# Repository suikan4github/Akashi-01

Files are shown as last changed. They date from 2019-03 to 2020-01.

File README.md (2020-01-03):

# Akashi-01
A Test jig board for the Murasaki library. Testing I2C, SPI, and UART on the Nucleo 64. This project is for Murasaki development. Not for the Murasaki application developer. 

## Functionality
This board is designed to test the serial port's functionality of the STM32 series MCU. The connectors can be directly mounted on the Nucleo 64 series board. With this board, the following can be tested :
- Serial Port TX and RX. With/without hardware handshake.
- I2C port Master and Slave. 
- SPI port Master and Slave. 

All above are achieved by connecting peripheral port head-to-head ( Serial port is an exception. It just tied TX to RX and RTS to CTS respectively). In addition to these test feature, additional parts can be mount : 
- Serial 7 segments LED display by Spark fun. 
- Rotary encoder with a switch to test the encoder functionality of timer and EXTI (External Interrupt of the STM32 MCU). 

## Development
- [KiCad 5.1](http://kicad-pcb.org/blog/2019/03/KiCad-5.1.0-Release/)
- [Nucleo F091RC](https://www.st.com/ja/evaluation-tools/nucleo-f091rc.html)
- [Nucleo L152RE](https://www.st.com/ja/evaluation-tools/nucleo-l152re.html)
- [Nucleo F446RE](https://www.st.com/ja/evaluation-tools/nucleo-f446re.html)

The schematics [can be downloaded](docs/Akashi-01.pdf) as PDF format. 

## Usage
The test program works with this board will be published as [murasaki_test_fundamental](https://github.com/suikan4github/murasaki_test_foundemental) project in future. 

If you develop a software works with this board, that software has to follow the pin configuration below. Note that the master-slave configuration is critical. If wrong, the MCU may be broken. 

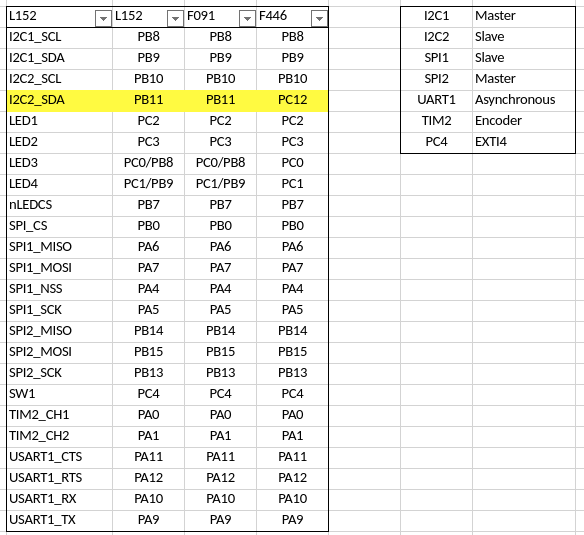
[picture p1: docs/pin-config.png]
Pin Configurations


I2C2_SDA is PB11 for both Nucleo L152RE and F091RC. But it is PC12 for the Nucleo F446RE.

**CAUTION** : Nucleo F446 CN10 pin 18 have to be cut. This pin is connected to VCAP1 pin of the STM32F446 internally. The VCAP1 is not for the peripheral usage. Thus, cutting pin 18 is not problem.

## License
This PCB design is released under the [Creative Commons Attribution 4.0 International license](https://creativecommons.org/licenses/by/4.0/). You are welcome to use this design for commercial purposes.

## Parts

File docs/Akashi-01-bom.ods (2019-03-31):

Reference | Value | Footprint | Datasheet | Field4
C1 | 0.01u | Capacitor_THT:C_Disc_D3.8mm_W2.6mm_P2.50mm | pin pitch = 2.50mm
C2 | 0.01u | Capacitor_THT:C_Disc_D3.8mm_W2.6mm_P2.50mm | pin pitch = 2.50mm
CN10 | PPPC192LFBN-RC | Connector_PinSocket_2.54mm:PinSocket_2x19_P2.54mm_Vertical | https://www.digikey.jp/product-detail/ja/sullins-connector-solutions/PPPC192LFBN-RC/S7122-ND/810258
CN7 | PPPC192LFBN-RC | Connector_PinSocket_2.54mm:PinSocket_2x19_P2.54mm_Vertical | https://www.digikey.jp/product-detail/ja/sullins-connector-solutions/PPPC192LFBN-RC/S7122-ND/810258
D1 | LED | LED_THT:LED_D3.0mm_Clear | pin pitch = 2.54mm
D2 | LED | LED_THT:LED_D3.0mm_Clear | pin pitch = 2.54mm
D3 | LED | LED_THT:LED_D3.0mm_Clear | pin pitch = 2.54mm
D4 | LED | LED_THT:LED_D3.0mm_Clear | pin pitch = 2.54mm
LED1 | SparkFun-7-Segment-Serial-Display-Red | Display_Modules:SparkFun-7-Segment-Serial-Display | https://www.sparkfun.com/products/11441 | COM-11441
R1 | 1k | Resistor_THT:R_Axial_DIN0207_L6.3mm_D2.5mm_P10.16mm_Horizontal | ¼ or 1/8 W
R10 | 10k | Resistor_THT:R_Axial_DIN0207_L6.3mm_D2.5mm_P10.16mm_Horizontal | ¼ or 1/8 W
R11 | 4.7k | Resistor_THT:R_Axial_DIN0207_L6.3mm_D2.5mm_P10.16mm_Horizontal | ¼ or 1/8 W
R2 | 1k | Resistor_THT:R_Axial_DIN0207_L6.3mm_D2.5mm_P10.16mm_Horizontal | ¼ or 1/8 W
R3 | 1k | Resistor_THT:R_Axial_DIN0207_L6.3mm_D2.5mm_P10.16mm_Horizontal | ¼ or 1/8 W
R4 | 1k | Resistor_THT:R_Axial_DIN0207_L6.3mm_D2.5mm_P10.16mm_Horizontal | ¼ or 1/8 W
R5 | 2.2k | Resistor_THT:R_Axial_DIN0207_L6.3mm_D2.5mm_P10.16mm_Horizontal | ¼ or 1/8 W
R6 | 10k | Resistor_THT:R_Axial_DIN0207_L6.3mm_D2.5mm_P10.16mm_Horizontal | ¼ or 1/8 W
R7 | 10k | Resistor_THT:R_Axial_DIN0207_L6.3mm_D2.5mm_P10.16mm_Horizontal | ¼ or 1/8 W
R8 | 10k | Resistor_THT:R_Axial_DIN0207_L6.3mm_D2.5mm_P10.16mm_Horizontal | ¼ or 1/8 W
R9 | 2.2k | Resistor_THT:R_Axial_DIN0207_L6.3mm_D2.5mm_P10.16mm_Horizontal | ¼ or 1/8 W
SW1 | PEC11R-4220F-S0024 | Rotary_Encoder:RotaryEncoder_Alps_EC12E-Switch_Vertical_H20mm_CircularMountingHoles | https://www.digikey.jp/products/ja?keywords=PEC11R-4220F-s0024
TP1 | nSS | TestPoint:TestPoint_THTPad_D1.5mm_Drill0.7mm | ~
TP10 | MOSI | TestPoint:TestPoint_THTPad_D1.5mm_Drill0.7mm | ~
TP11 | GND | TestPoint:TestPoint_THTPad_D1.5mm_Drill0.7mm | ~
TP12 | GND | TestPoint:TestPoint_THTPad_D1.5mm_Drill0.7mm | ~
TP2 | CH1 | TestPoint:TestPoint_THTPad_D1.5mm_Drill0.7mm | ~
TP3 | CH2 | TestPoint:TestPoint_THTPad_D1.5mm_Drill0.7mm | ~
TP4 | SCL | TestPoint:TestPoint_THTPad_D1.5mm_Drill0.7mm | ~
TP5 | TX | TestPoint:TestPoint_THTPad_D1.5mm_Drill0.7mm | ~
TP6 | SDA | TestPoint:TestPoint_THTPad_D1.5mm_Drill0.7mm | ~
TP7 | SCK | TestPoint:TestPoint_THTPad_D1.5mm_Drill0.7mm | ~
TP8 | RTS | TestPoint:TestPoint_THTPad_D1.5mm_Drill0.7mm | ~
TP9 | MISO | TestPoint:TestPoint_THTPad_D1.5mm_Drill0.7mm | ~

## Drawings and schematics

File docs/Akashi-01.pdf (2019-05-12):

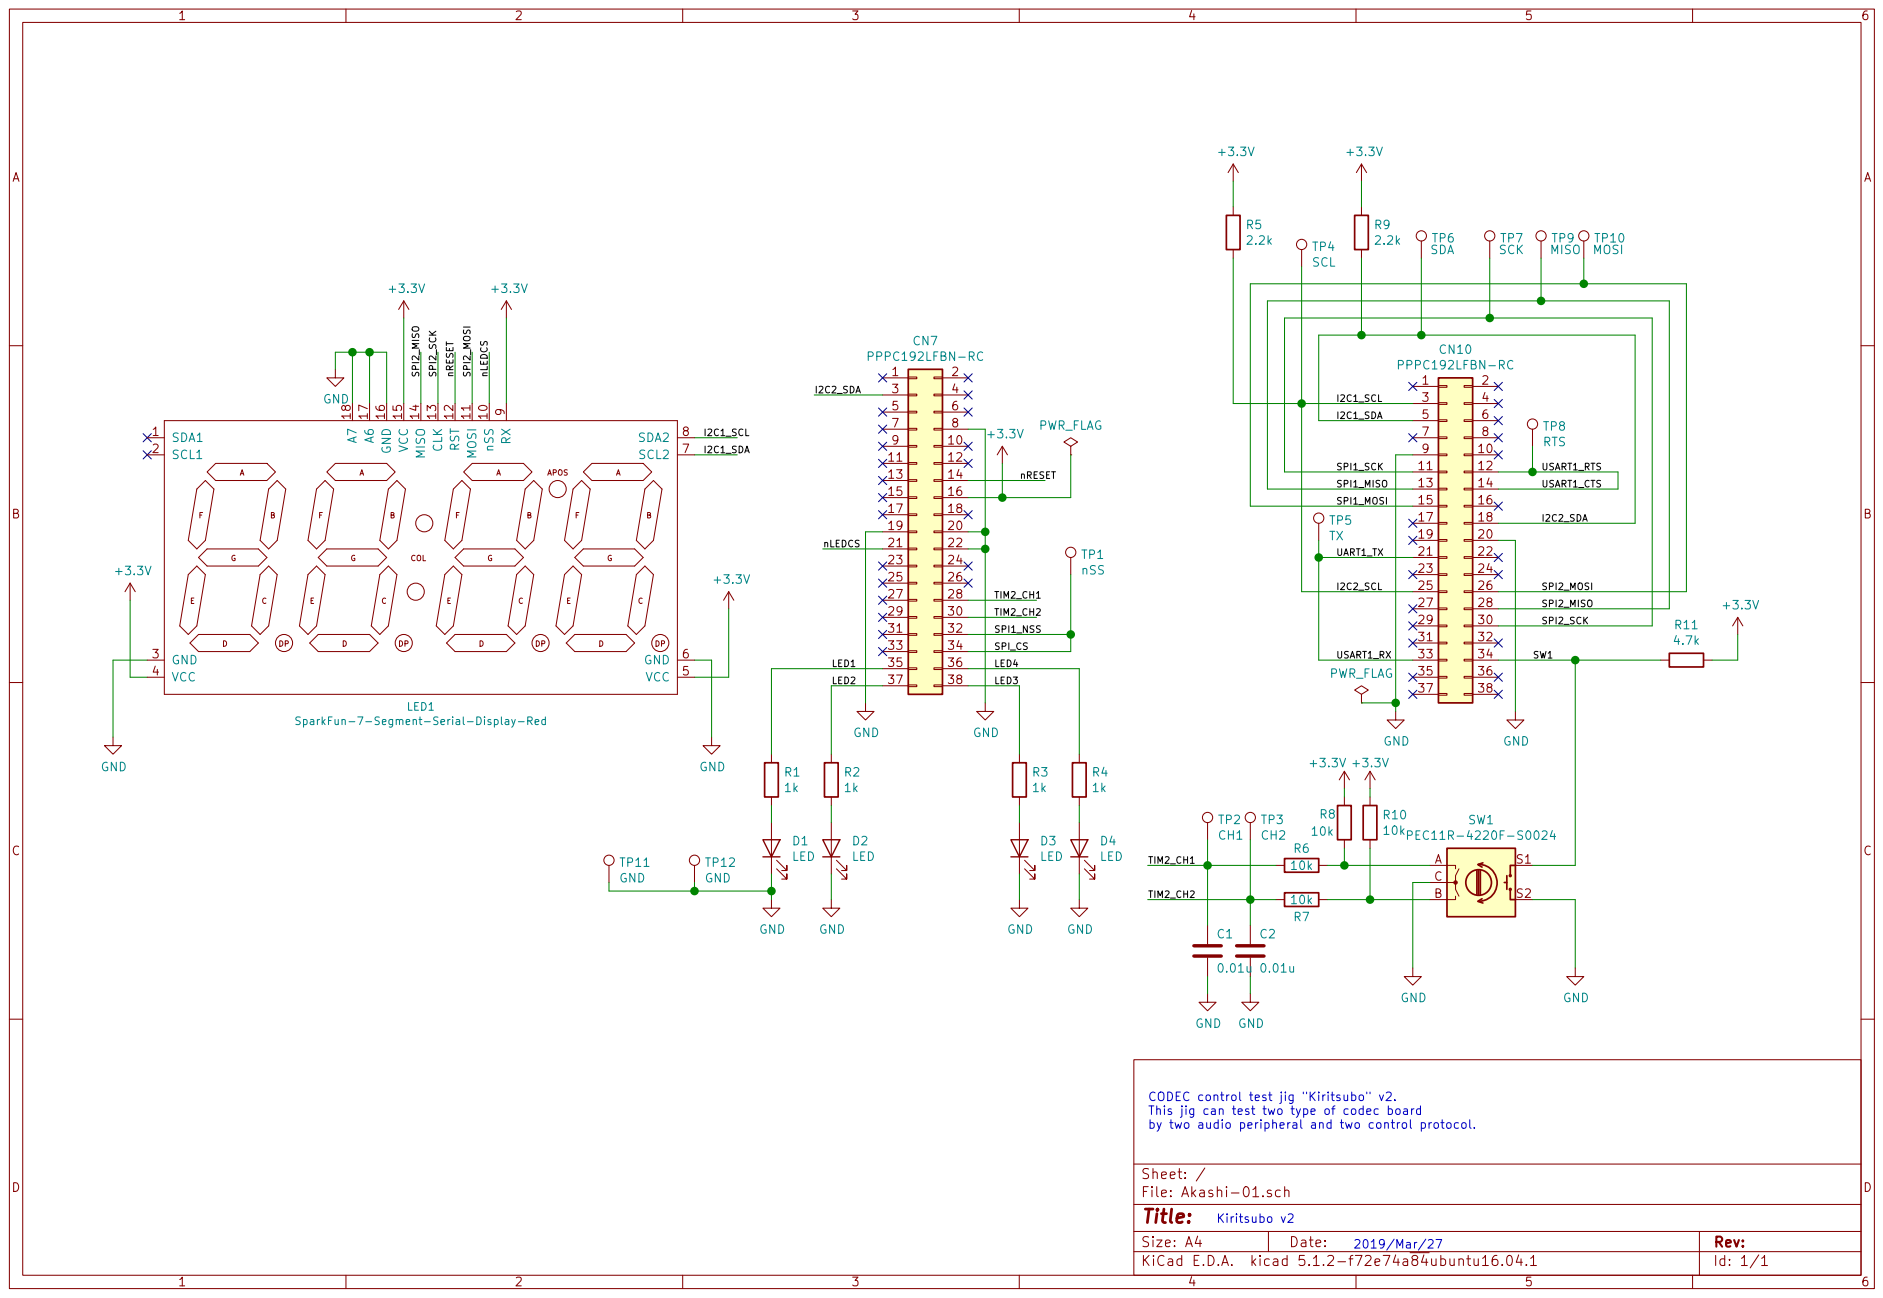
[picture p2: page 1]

SPI1_MISO | 13 | 14

15 | 16 18 I2C2_SDA
17

LED1 SparkFun-7-Segment-Serial-Display-Red

2019/Mar/27 CODEC control test jig "Kiritsubo" v2.
This jig can test two type of codec board
by two audio peripheral and two control protocol.

Id: 1/1 Title: File: Akashi-01.sch Sheet: /

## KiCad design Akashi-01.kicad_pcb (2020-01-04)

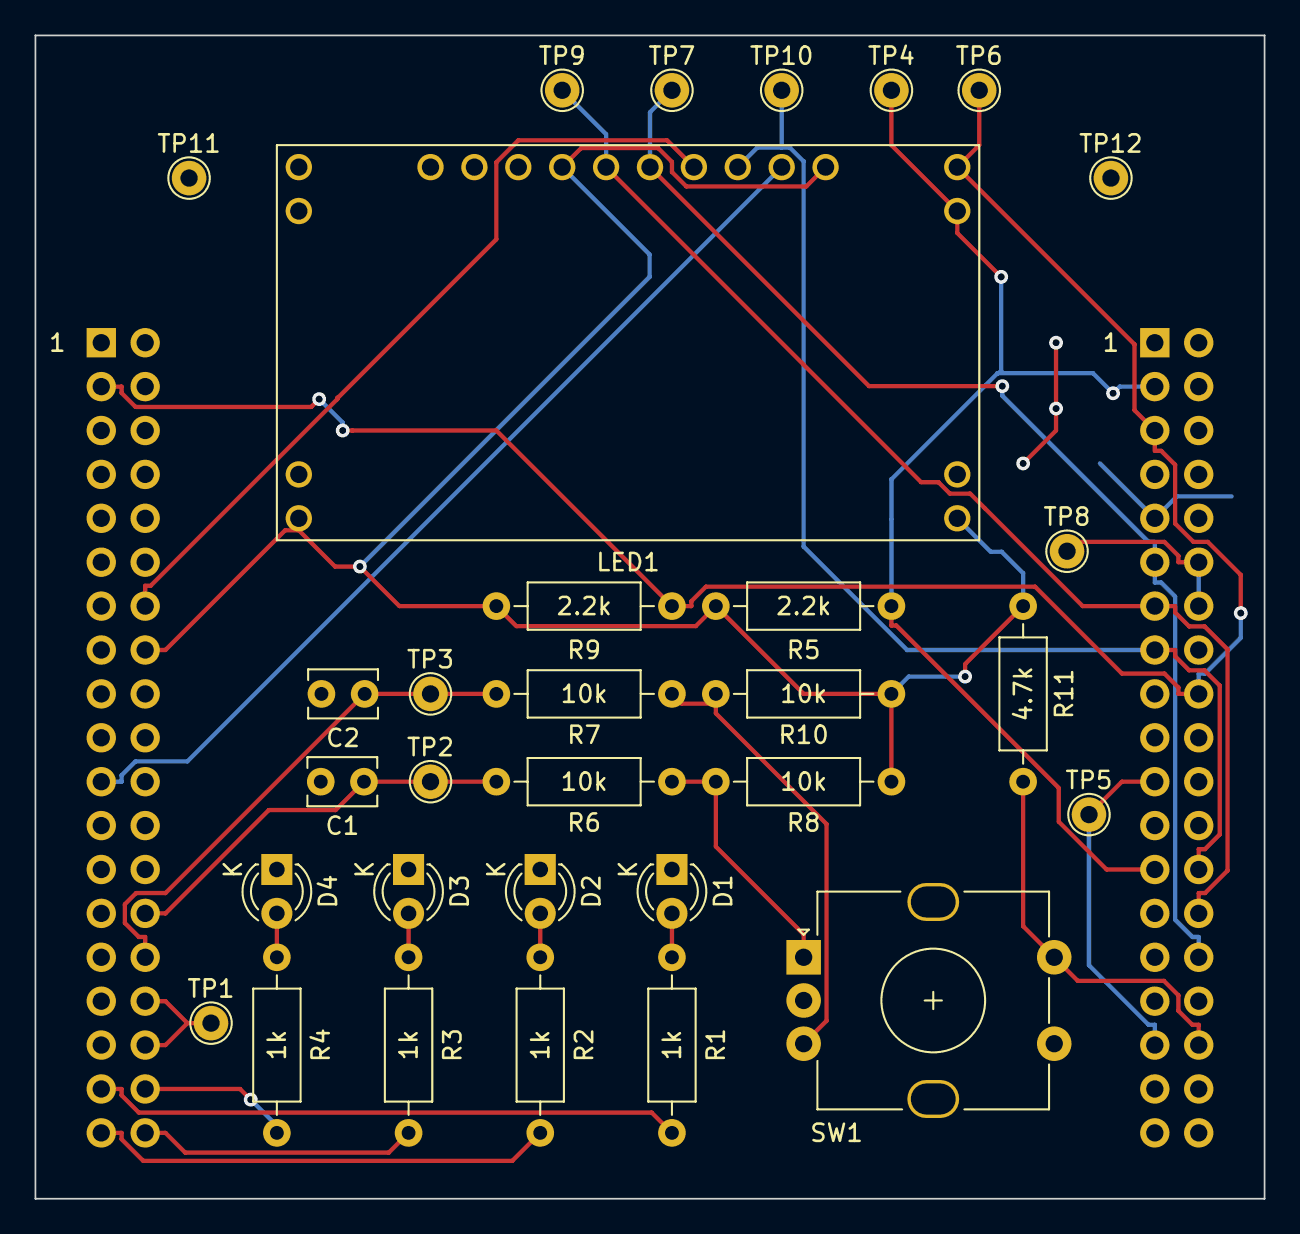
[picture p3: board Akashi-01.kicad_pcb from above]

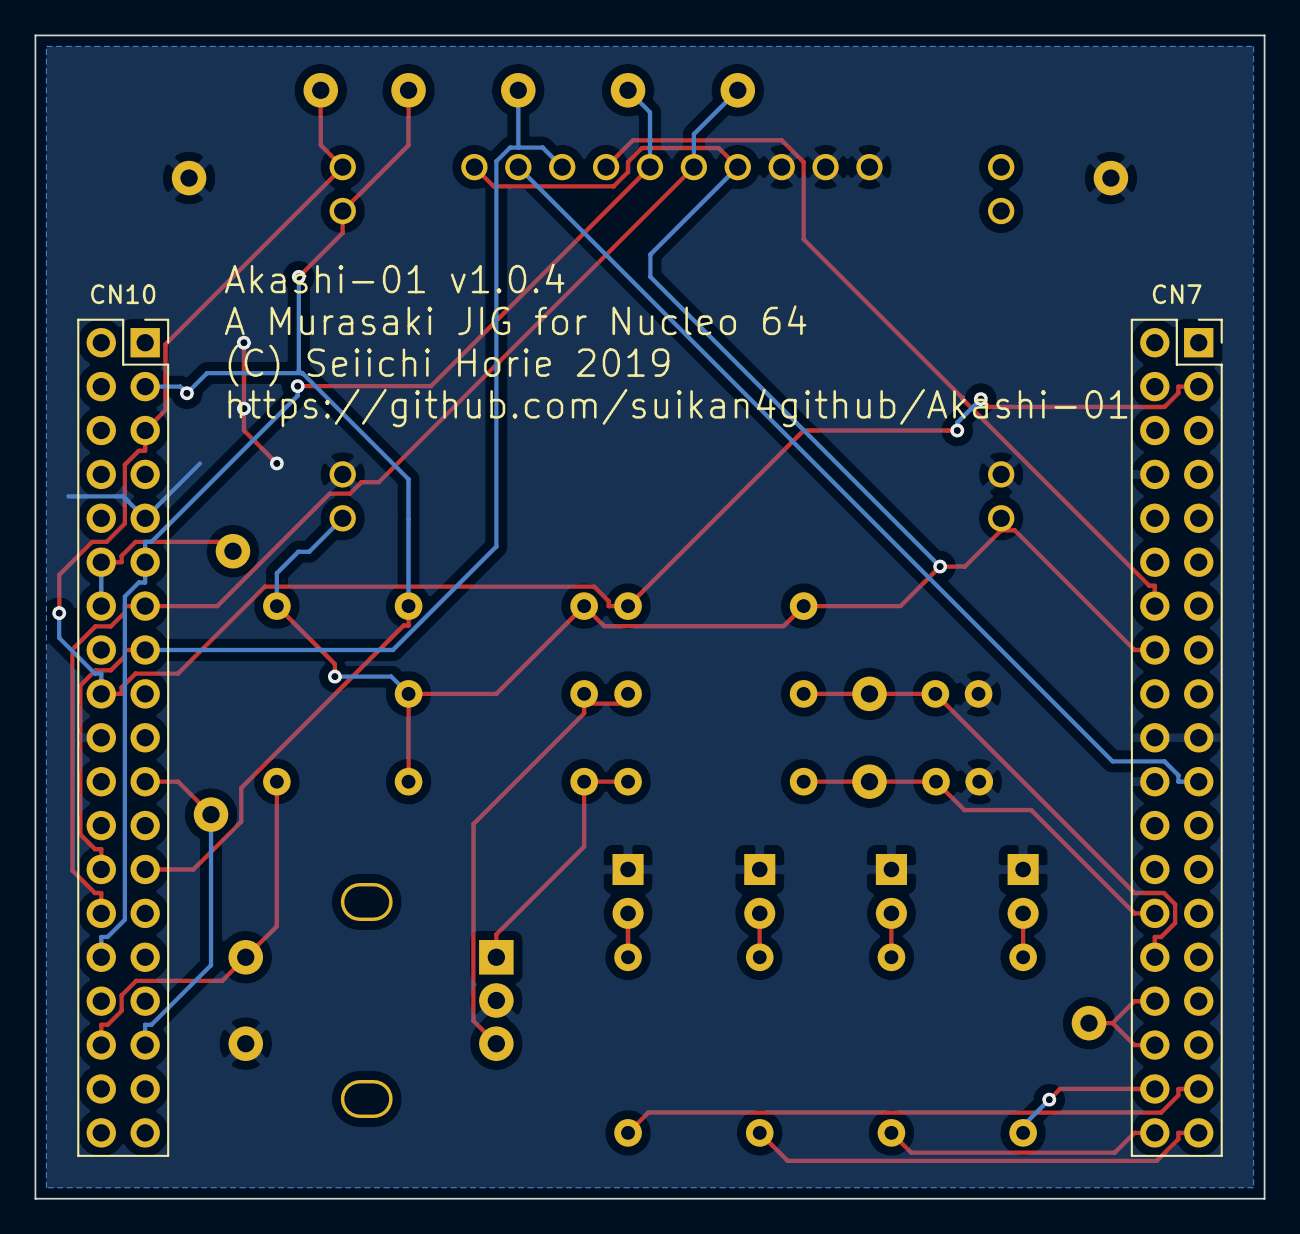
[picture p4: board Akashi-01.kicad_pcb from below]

Board: 2 copper layers, 71.1 x 67.3 mm, 33 parts (2 on the bottom side), 25 nets.

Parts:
C1, C2: 0.01u; C_Disc_D3.8mm_W2.6mm_P2.50mm
CN7, CN10: PPPC192LFBN-RC; PinSocket_2x19_P2.54mm_Vertical
D1, D2, D3, D4: LED; LED_D3.0mm_Clear
LED1: SparkFun-7-Segment-Serial-Display-Red; SparkFun-7-Segment-Serial-Display
R1, R2, R3, R4: 1k; R_Axial_DIN0207_L6.3mm_D2.5mm_P10.16mm_Horizontal
R5, R9: 2.2k; R_Axial_DIN0207_L6.3mm_D2.5mm_P10.16mm_Horizontal
R6, R7, R8, R10: 10k; R_Axial_DIN0207_L6.3mm_D2.5mm_P10.16mm_Horizontal
R11: 4.7k; R_Axial_DIN0207_L6.3mm_D2.5mm_P10.16mm_Horizontal
SW1: PEC11R-4220F-S0024; RotaryEncoder_Alps_EC12E-Switch_Vertical_H20mm_CircularMoun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
TP1: nSS; TestPoint_THTPad_D2.0mm_Drill1.0mm
TP2: CH1; TestPoint_THTPad_D2.0mm_Drill1.0mm
TP3: CH2; TestPoint_THTPad_D2.0mm_Drill1.0mm
TP4: SCL; TestPoint_THTPad_D2.0mm_Drill1.0mm
TP5: TX; TestPoint_THTPad_D2.0mm_Drill1.0mm
TP6: SDA; TestPoint_THTPad_D2.0mm_Drill1.0mm
TP7: SCK; TestPoint_THTPad_D2.0mm_Drill1.0mm
TP8: RTS; TestPoint_THTPad_D2.0mm_Drill1.0mm
TP9: MISO; TestPoint_THTPad_D2.0mm_Drill1.0mm
TP10: MOSI; TestPoint_THTPad_D2.0mm_Drill1.0mm
TP11, TP12: GND; TestPoint_THTPad_D2.0mm_Drill1.0mm

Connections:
+3V3: CN7.16, LED1.4, LED1.5, LED1.9, LED1.15, R5.1, R8.1, R9.1, R10.1, R11.1
/I2C1_SCL: CN10.3, CN10.25, LED1.7, R5.2, TP4.1
/I2C1_SDA: CN7.3, CN10.5, CN10.18, LED1.8, R9.2, TP6.1
/LED1: CN7.35, R1.1
/LED2: CN7.37, R2.1
/LED3: CN7.38, R3.1
/LED4: CN7.36, R4.1
/SPI1_MISO: CN10.13, CN10.28, LED1.14, TP9.1
/SPI1_MOSI: CN10.15, CN10.26, LED1.11, TP10.1
/SPI1_NSS: CN7.32, CN7.34, TP1.1
/SPI1_SCK: CN10.11, CN10.30, LED1.13, TP7.1
/SW1: CN10.34, R11.2, SW1.S1
/TIM2_CH1: C1.1, CN7.28, R6.2, TP2.1
/TIM2_CH2: C2.1, CN7.30, R7.2, TP3.1
/UART1_TX: CN10.21, CN10.33, TP5.1
/USART1_CTS: CN10.12, CN10.14, TP8.1
/nLEDCS: CN7.21, LED1.10
/nRESET: CN7.14, LED1.12
GND: C1.2, C2.2, CN7.8, CN7.19, CN7.20, CN7.22, CN10.9, CN10.20, D1.1, D2.1, D3.1, D4.1, LED1.3, LED1.6, LED1.16, LED1.17, LED1.18, SW1.C, SW1.S2, TP11.1, TP12.1
unnamed: D1.2, R1.2
unnamed: D2.2, R2.2
unnamed: D3.2, R3.2
unnamed: D4.2, R4.2
unnamed: R6.1, R8.2, SW1.A
unnamed: R7.1, R10.2, SW1.B

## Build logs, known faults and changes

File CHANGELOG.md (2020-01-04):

# Change log
Record of the modification in project development.
## [Unreleased]
- [Issue 11 : The Silk have to be updated ](https://github.com/suikan4github/Akashi-01/issues/11)

### Added
### Changed
### Deprecated
### Removed
### Fixed

### Security
### Known Issue

## [1.0.4] - 2020-01-04

### Added
### Changed
### Deprecated
### Removed
### Fixed
### Security
### Known Issue

## [1.0.3] - 2020-01-04

### Added
### Changed
### Deprecated
### Removed
### Fixed
- [Issue 5 : Make thirdparty library access to internal ](https://github.com/suikan4github/Akashi-01/issues/5)
- [Issue 7 : LED1 module SCL/SDA is connected reverse ](https://github.com/suikan4github/Akashi-01/issues/7)
- [Issue 8 : SW1 mount point hall is too small ](https://github.com/suikan4github/Akashi-01/issues/8)
- [Issue 9 : Need description of the CN10 pin 18 ](https://github.com/suikan4github/Akashi-01/issues/9)

### Security
### Known Issue

## [1.0.2] - 2019-05-12

### Added
### Changed
### Deprecated
### Removed
### Fixed
- [Issue 4 : schematic with wrong pin assign Serial 7 segment display. ](https://github.com/suikan4github/Akashi-01/issues/4)

### Security
### Known Issue

## [1.0.1] - 2019-04-14

### Added
### Changed
- [Issue 2 : Copyright is too small ](https://github.com/suikan4github/Akashi-01/issues/2)

### Deprecated
### Removed
### Fixed
- [Issue 1 : Test point hole is too small  ](https://github.com/suikan4github/Akashi-01/issues/1)
- [Issue 3 : Update frootprint of the serial display ](https://github.com/suikan4github/Akashi-01/issues/3)

### Security
### Known Issue

## [1.0.0] - 2019-03-01
Initial release. 

### Added
### Changed
### Deprecated
### Removed
### Fixed
### Security

[Unreleased]: https://github.com/suikan4github/Akashi-01/compare/v1.0.4...develop
[1.0.4]: https://github.com/suikan4github/Akashi-01/compare/v1.0.3...v1.0.4
[1.0.3]: https://github.com/suikan4github/Akashi-01/compare/v1.0.2...v1.0.3
[1.0.2]: https://github.com/suikan4github/Akashi-01/compare/v1.0.1...v1.0.2
[1.0.1]: https://github.com/suikan4github/Akashi-01/compare/v1.0.0...v1.0.1

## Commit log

2019-03-28 Moved from the old project
    [Akashi-01.kicad_pcb, Akashi-01.sch]
2019-03-31 Gerber generated.
    The gerber was sent to fab Mar/31/2019.
    Added schematics and README.md
    [Akashi-01.kicad_pcb, Akashi-01.ods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]
2019-03-31 Prepare to publish
    [Akashi-01-bom.ods, Akashi-01-pin-config.ods]
2019-04-14 Change the copy right size.
    From 1.0 to 1.5
    Issue : Copyright is too small #2
    https://github.com/suikan4github/Akashi-01/issues/2
    [Akashi-01.kicad_pcb]
2019-04-14 Change test point drill size.
    Issue 1 : Test point hole is too small #1
    https://github.com/suikan4github/Akashi-01/issues/1
    [Akashi-01.kicad_pcb, Akashi-01.sch]
2019-04-14 Change footprint
    Issue 3 : Update frootprint of the serial display #3
    https://github.com/suikan4github/Akashi-01/issues/3
    [Akashi-01.kicad_pcb]
2019-04-14 Generate gerber
    [pcb.drl, pcb.gbl, pcb.gbo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]
2019-05-12 Serial LED has been fixed.
    Issue : Serial 7 segment module has wrong pin assigment. #3
    https://github.com/suikan4github/Suikan-KiCad-Libraries/issues/3
    [Akashi-01.kicad_pcb, Akashi-01.sch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]
2019-05-12 Update CHANGELOG
    Issue : schematic with wrong pin assign Serial 7 segment display. #4
    https://github.com/suikan4github/Akashi-01/issues/4
2019-05-12 Update schematic
2019-11-04 Fixed comment on the Schematics and README
    [Akashi-01.sch]
2020-01-03 Modify the mistaken connection of SCL/SDA to LED module.
    LED1 module SCL/SDA is connected reverse. #7
    https://github.com/suikan4github/Akashi-01/issues/7
    [Akashi-01.kicad_pcb, Akashi-01.sch]
2020-01-03 Change the SW1 mount hole.
    Issue 8 : SW1 mount point hall is too small
    https://github.com/suikan4github/Akashi-01/issues/8
    [Akashi-01.kicad_pcb]
2020-01-03 Added CN10 Pin 18 note to readme.
    Issue 9 : Need description of the CN10 pin 18
    https://github.com/suikan4github/Akashi-01/issues/9
2020-01-04 Silk updated.
    Issue 11 : The Silk have to be updated
    https://github.com/suikan4github/Akashi-01/issues/11
    [Akashi-01.kicad_pcb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]
